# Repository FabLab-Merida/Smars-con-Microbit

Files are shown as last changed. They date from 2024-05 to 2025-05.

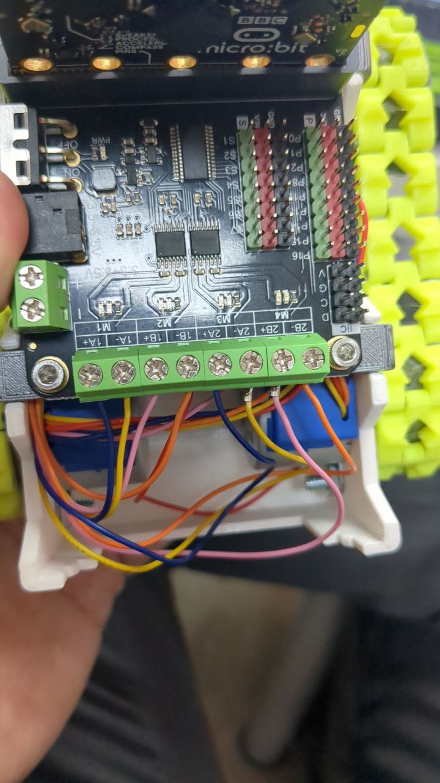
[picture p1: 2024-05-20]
Code/MotorPasoAPaso/CableadoMotorPasoAPaso.jpg

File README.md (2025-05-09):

# Smars con Microbit
 Smars with Microbit project we did for the CITlab centers (Extremadura)
 Smars con Microbit de los proyectos CITlab

 Updates:
   * Added magnetic gripper, a modification that requires the servo arm from the capacitive sensor and ⌀8mm magnets.
 
 Other Links//Otros links:
   * Original SMARS: https://www.thingiverse.com/thing:2662828
   * TPU/Rubber wheels: https://www.thingiverse.com/thing:3313618
   * Original Soil Moisture sensor: https://www.thingiverse.com/thing:2829488
   * Forklift Mod: https://www.thingiverse.com/thing:3027255

 
 PXL_20240521_102033709 MP 
 PXL_20240521_095141264~2

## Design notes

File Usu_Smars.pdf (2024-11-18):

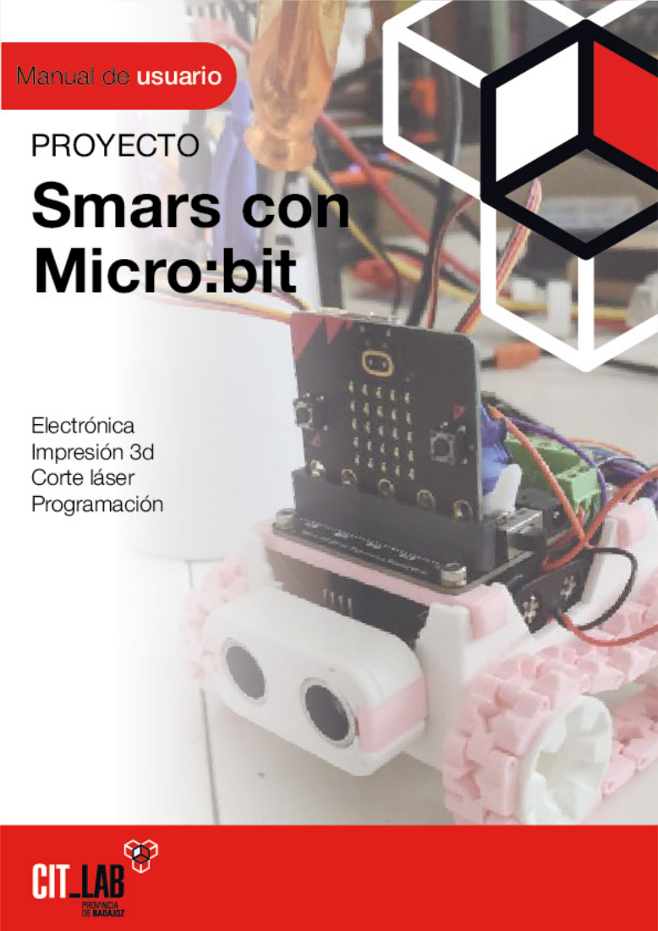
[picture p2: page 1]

# COMPONENTES

2

Este manual ha sido realizado por el equipo de la asociación FABlab Mérida para el proyecto CITLab de la Diputación de Badajoz.
Equipo técnico: Alberto Cañaveras Solís, Carlos Gómez-Landero Hernández, Javier García González, Javier García Arias, Javier Conejero Rodríguez, Juan Luis Arenas Sánchez, Pablo Augusto Gordillo Caro y Víctor Gallardo Sánchez.
Redacción de contenidos: Javier García González. Diseñador gráfico: Javier García González.
Maquetación: Javier García González.
Revisión: Javier García Arias, Juan Luis Arenas Sánchez, Julián Ortega Durán, Mercedes García Burrel y Víctor Gallardo Sánchez.
Todos los nombres propios de programas, sistemas operativos, equipos hardware, etc. que aparecen en este libro son marcas registradas de sus respectivas compañías u organizaciones.
Manual de usuario del Proyecto SMARS © 2024 by FA-Blab Mérida is licensed under CC BY-NC-SA 4.0

# ÍNDICE

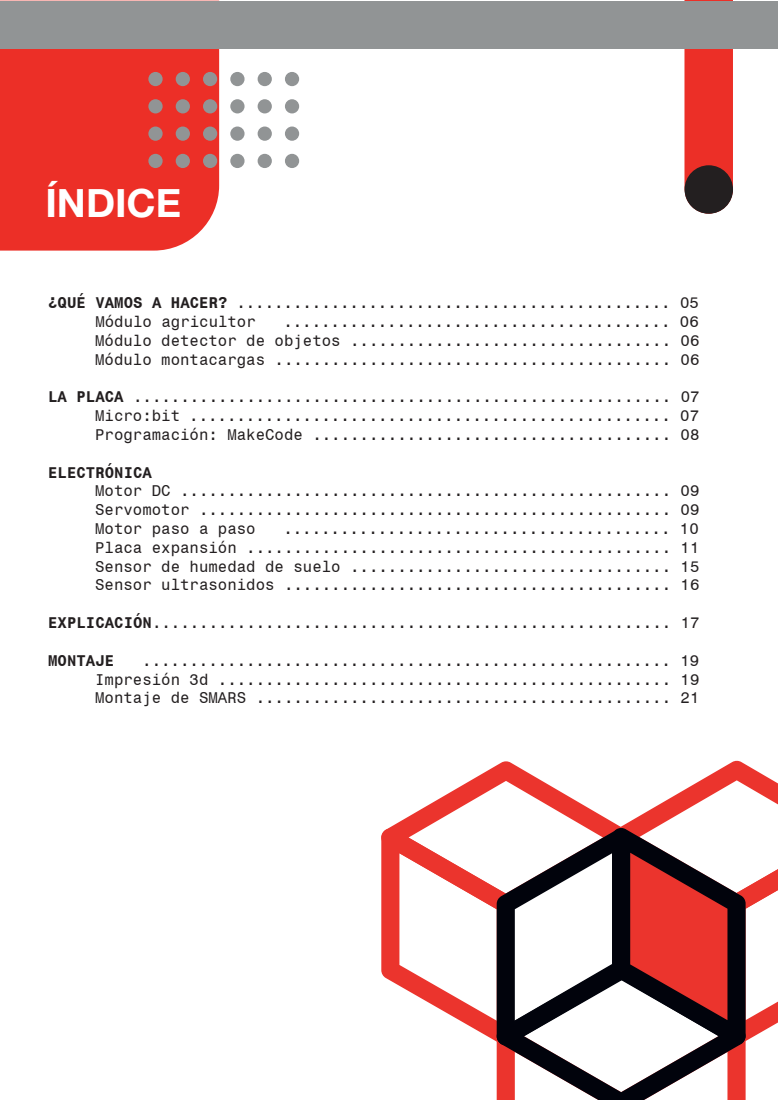
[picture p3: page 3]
ELECTRÓNICA

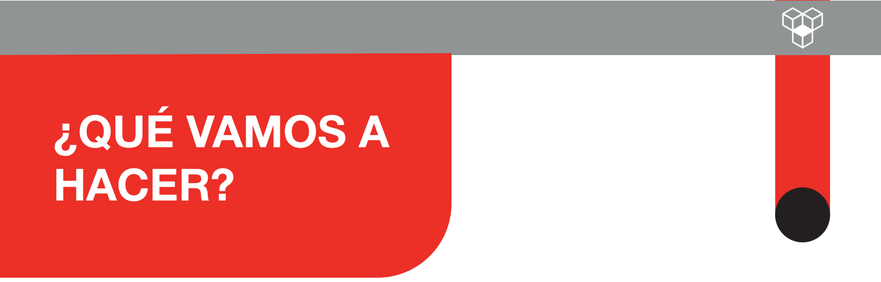
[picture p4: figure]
¿QUÉ VAMOS A HACER?

5

Los SMARS son un proyecto abierto donde han colaborado muchas personas que tienen como objetivo montar vehículos robóticos dirigidos a la educación. Estos robots están creados a partir de ensamblajes modulares sin necesidad de tornillos.
En este proyecto se pretende construir un smars basándonos en micro:bit con el que conocer las posibilidades de esta placa para la educación en programación y robótica. Además, se ofrecen distintas alternativas para que sea un proyecto dinámico y modular, como inicio al mundo de los SMARS.

Temática

Impresión 3d

Programación
básica

Electrónica
básica

Robótica

Materiales

Filamento PLA de tipos

Filamento TPU (opcional)

Tornillos M3x5mm | x4
Portapilas 4xAA | x1
Pilas AA | x4

Electrónica

Micro:bit | x1

Placa de expansión
Micro:bit Motor Expansion
| x1
Motor* | x2

# Smars básico

* Para empezar, se han añadido diversas opciones de montaje de motores:
- Servomotor 360º
- Motor paso a paso
- Motor DC 6V 150RPM
Cada uno de los motores requiere de una programación y modelo distinto, que se debe tener en cuenta en el desarrollo del prototipo.

# COMPONENTES

6

# ¿QUÉ VAMOS A HACER?

Materiales

Filamento PLA dos colores

Electrónica

Sensor capacitivo humedad

# Módulo agricultor

Con este módulo, se añade un sensor de humedad de tierra que puede pincharse en el suelo para comprobar su humedad y mapear la humedad del suelo siguiendo un recorrido.

Materiales

Filamento PLA dos colores

Materiales

Filamento PLA de dos tipos

Electrónica

Sensor de ultrasonidos . x1

Electrónica

Motor DC 6V 60RPM M3 5cm x1

# Módulo detector de objetos

# Módulo montacargas

Con este módulo se añade un sensor de ultrasonidos que permite la detección de objetos frente al SMARS y la posibilidad de esquivarlo.

Con este módulo, se puede sujetar objetos del suelo para desplazarlos de un lado a otro.

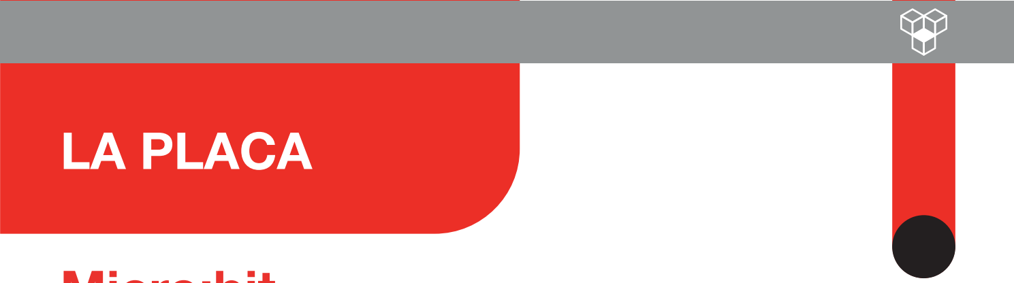
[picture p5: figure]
LA PLACA

7 7

Micro:bit es una pequeña placa de desarrollo diseñada por la BBC para enseñar programación y computación en la educación primaria y secundaria. Es una herramienta educativa que permite a los estudiantes aprender conceptos básicos de programación y electrónica de una manera práctica y divertida.

# Micro:bit

Entradas del micro:bit y sensores integrados:

Echa un vistazo al QR si quieres saber más.

Micro:bit posee varias entradas y salidas para conectarse con otros dispositivos:
3 Entradas salidas digitales
4 Salida de 3V
5 Pin de tierra
También tiene sensores integrados para tener una iniciación más rápida.
Frontal
1 Botón A y B
2 Matriz de 5x5 leds
6 Logo con sensor táctil
Trasera
1 Antena de radio y bluetooth
2 Sensor de temperatura
3 4 Acelerómetro y osciloscopio 5 Pines
6 Entrada Micro USB
9 Entrada de batería
Altavoz
Micrófono
Botón de reset

11
12
13

# LA PLACA

# Programación: MakeCode

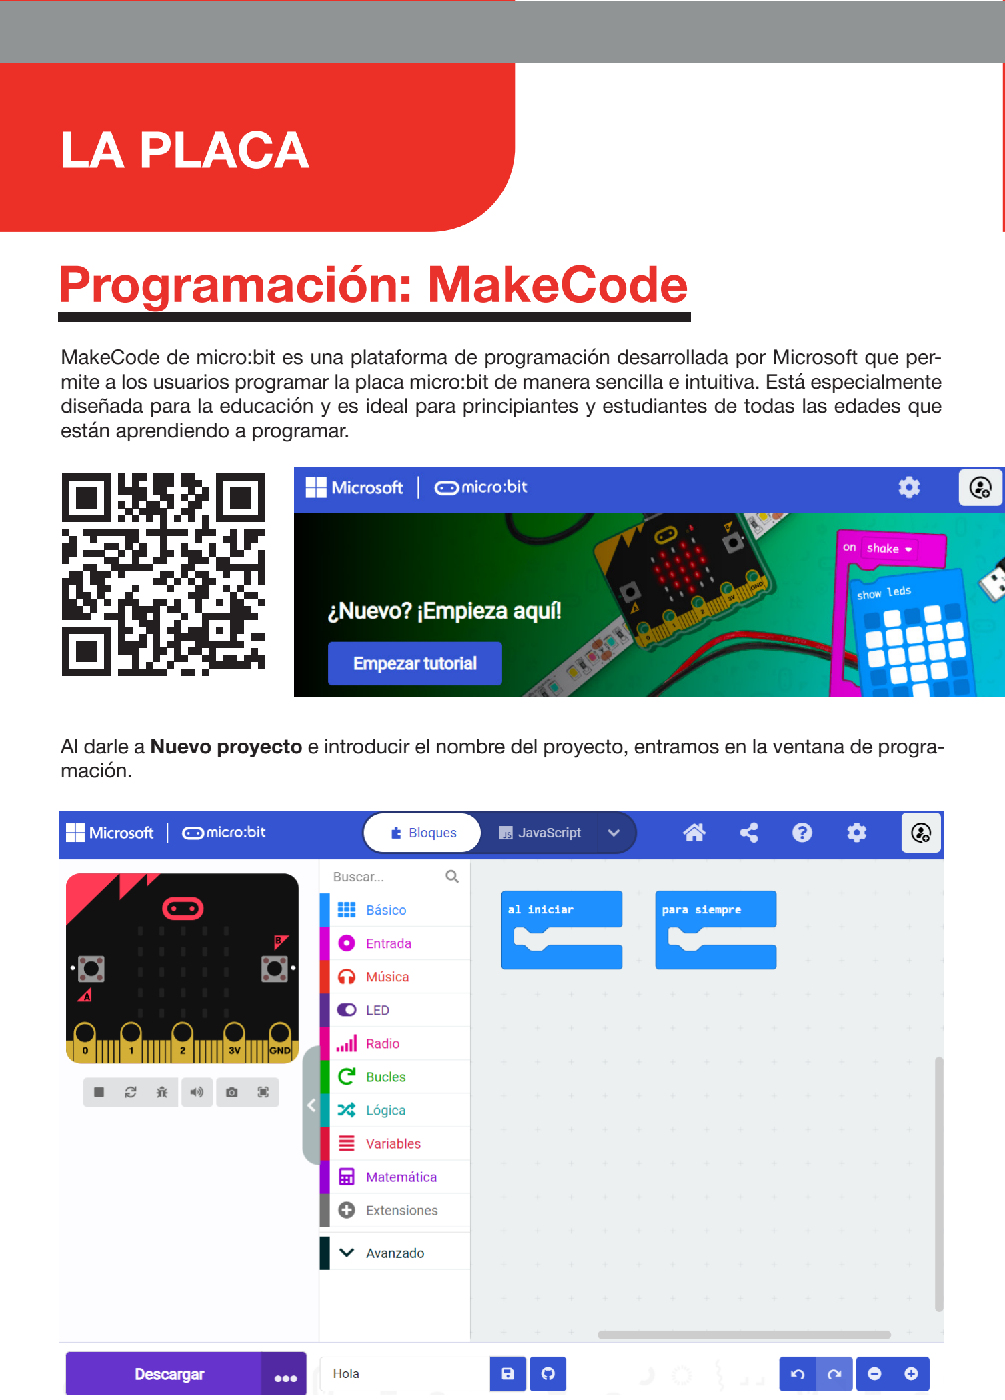
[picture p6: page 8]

MakeCode de micro:bit es una plataforma de programación desarrollada por Microsoft que permite a los usuarios programar la placa micro:bit de manera sencilla e intuitiva. Está especialmente diseñada para la educación y es ideal para principiantes y estudiantes de todas las edades que están aprendiendo a programar.

Al darle a Nuevo proyecto e introducir el nombre del proyecto, entramos en la ventana de programación.

9

Microbit: las salidas PWM
«PWM» significa «Modulación de Ancho de Pulso» en inglés (Pulse Width Modulation). Es una técnica utilizada en electrónica para controlar la cantidad de energía entregada a un dispositivo, mediante la variación del ancho de los pulsos de una señal eléctrica. Posee un funcionamiento distinto al del resto de pines digitales si se le indica.

Un motor DC es un motor que funciona por corriente contínua. Su propia fabricación hace que, si se le alimenta con una mayor tensión, se obtengan mayores revoluciones. Solo requiere de una entrada de corriente y una de tierra

Estos dispositivos son comúnmente utilizados en proyectos y dispositivos que requieren movimiento controlado, como juguetes, robots, modelismo, y otras aplicaciones.

La característica principal de un servomotor es su capacidad para girar hasta un ángulo determinado en respuesta a señales eléctricas. La mayoría de los servomotores comerciales para proyectos electrónicos tienen un rango de movimiento de 0 a 180 grados, aunque también existen modelos que pueden girar 360 grados. En nuestro proyecto utilizaremos dos servomotores que deben ser de 360º para mover las ruedas. En caso de que sean de 180º, este proyecto no sería posible con este tipo de motor.

# Servomotor

Pines de un servo
- Señal (PWM): Pin que le proporciona la señal digital que le indicará al servomotor la posición a la que debe girar. Debe conectarse a un pin PWM.
- Positivo (+): entrada de 5V del Arduino.
- Negativo (-): salida a GND del Arduino.
+

s

Un servomotor es un dispositivo que permite controlar y posicionar un eje en ángulos específicos. A diferencia de los motores convencionales, los servomotores están diseñados para un control preciso de la posición angular.

Cómo funciona un servomotor:

10

# COMPONENTES

# Motor Paso a paso

Un motor paso a paso es un tipo de motor similar a los servos. Al igual que ellos, se puede regular la posición del eje del motor con mucha precisión. Para ello, en vez de utilizar ángulos, se emplean pasos, que son pequeños desplazamientos de rotación.
En nuestro caso, los motores tienen 20 posiciones distintas.

Pines de un motor paso a paso
Este tipo de motores requiere usualmente de una placa intermedia para funcionar al que se conectan siguiendo la distribución indicada abajo:

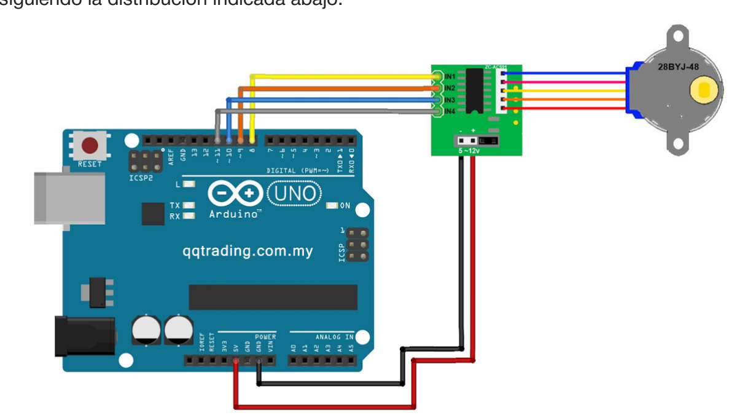
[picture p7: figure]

Sin embargo, en nuestro proyecto utilizaremos una placa de expansión de motores adaptada a micro:bit.

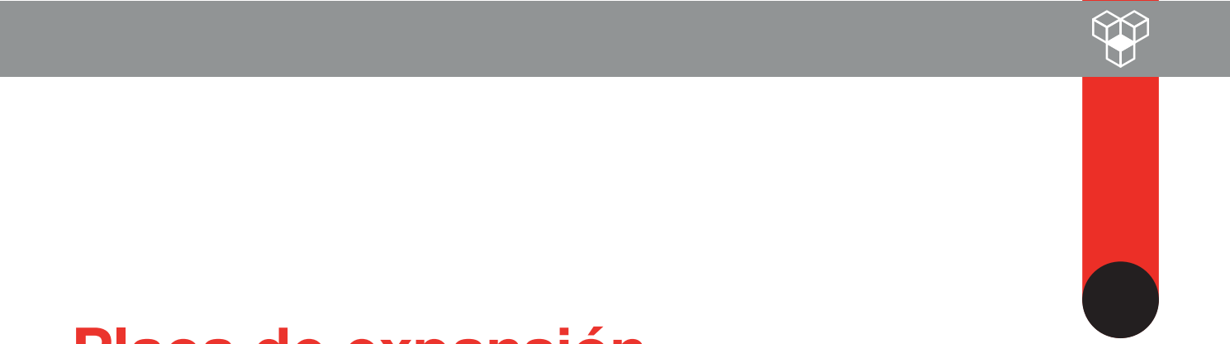
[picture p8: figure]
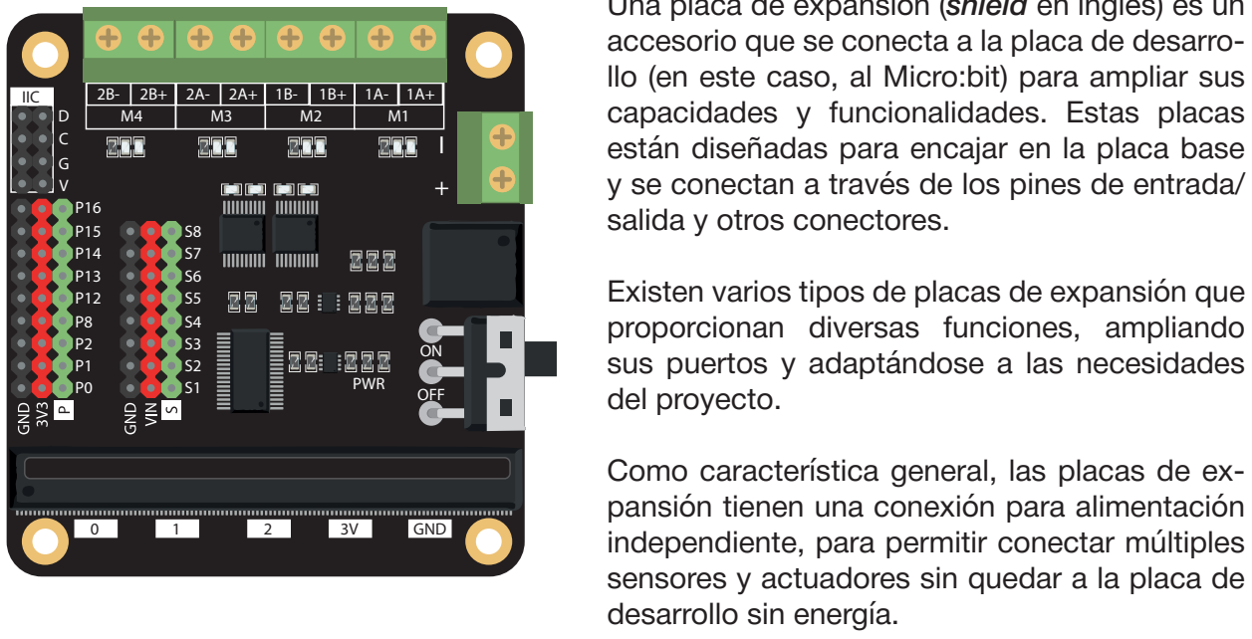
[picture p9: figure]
capacidades y funcionalidades. Estas placas; salida y otros conectores.; proporcionan diversas funciones, ampliando; del proyecto.; independiente, para permitir conectar múltiples; desarrollo sin energía.; IIC; GND; OFF PWR

11

Una placa de expansión (shield en inglés) es un accesorio que se conecta a la placa de desarrollo (en este caso, al Micro:bit) para ampliar sus están diseñadas para encajar en la placa base y se conectan a través de los pines de entrada/

Existen varios tipos de placas de expansión que sus puertos y adaptándose a las necesidades

Como característica general, las placas de expansión tienen una conexión para alimentación sensores y actuadores sin quedar a la placa de

# Placa de expansión

0 | 1 | 2 | 3V | GND

Funcionamiento de la placa de expansión

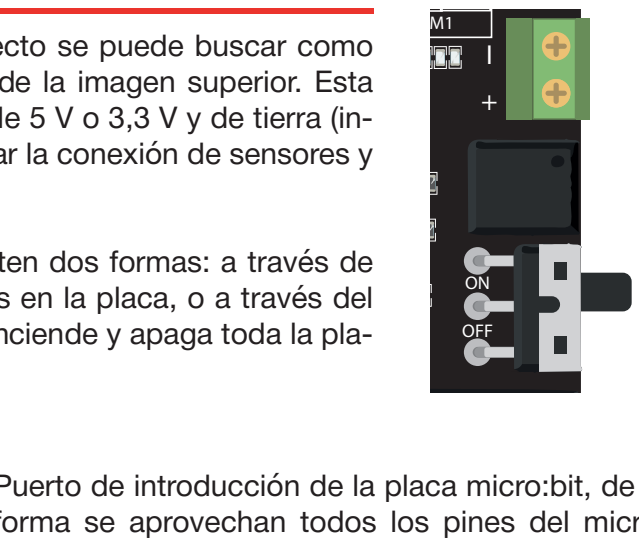
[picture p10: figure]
OFF PWR

La placa que se quiere utilizar en este proyecto se puede buscar como Micro:Bit Motor Expansion y tiene la forma de la imagen superior. Esta placa añade a cada pin del micro:bit un pin de 5 V o 3,3 V y de tierra (indicado en las placas como GND), para facilitar la conexión de sensores y actuadores.
Para alimentar esta placa de expansión existen dos formas: a través de dos cables introducidos en el - y + indicados en la placa, o a través del puerto de al lado. Existe un interruptor que enciende y apaga toda la placa.

Puerto de introducción de la placa micro:bit, de esta forma se aprovechan todos los pines del micro:bit para conectar multitud de sensores y actuadores.

# COMPONENTES

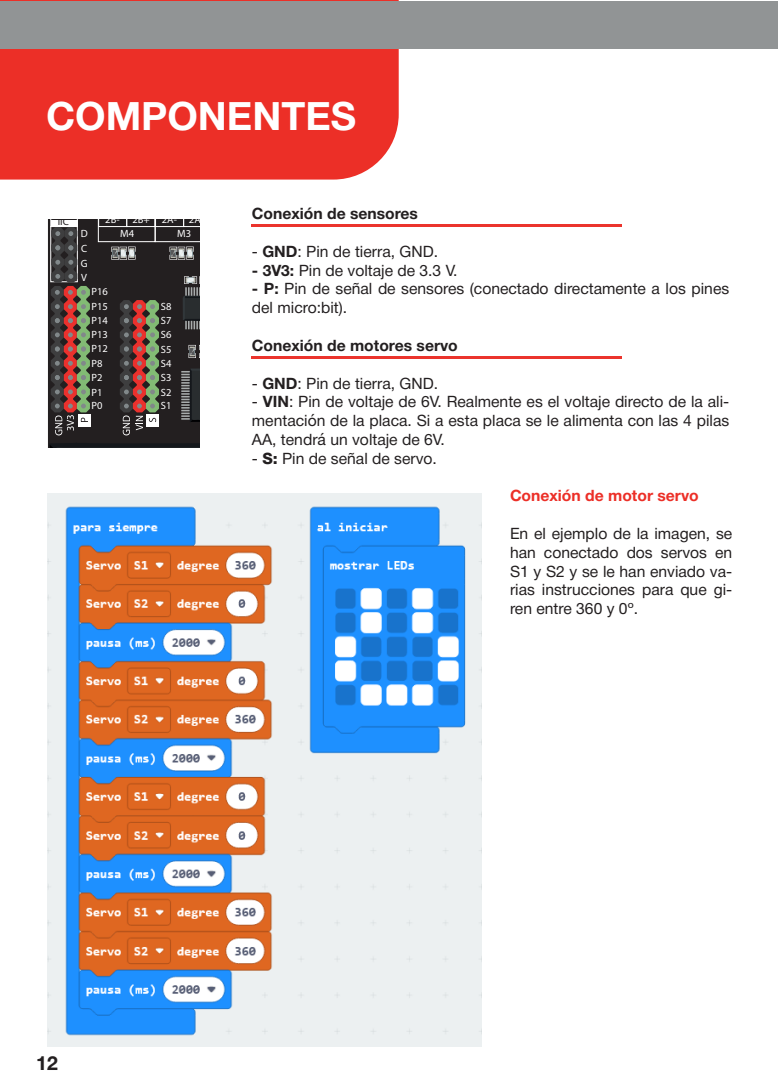
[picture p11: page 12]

Conexión de sensores
- GND: Pin de tierra, GND.
- 3V3: Pin de voltaje de 3.3 V.
- P: Pin de señal de sensores (conectado directamente a los pines
del micro:bit).
Conexión de motores servo
- VIN: Pin de voltaje de 6V. Realmente es el voltaje directo de la ali-
mentación de la placa. Si a esta placa se le alimenta con las 4 pilas
AA, tendrá un voltaje de 6V.
- S: Pin de señal de servo.

Conexión de motor servo
En el ejemplo de la imagen, se
han conectado dos servos en
S1 y S2 y se le han enviado va-
rias instrucciones para que gi-
ren entre 360 y 0º.

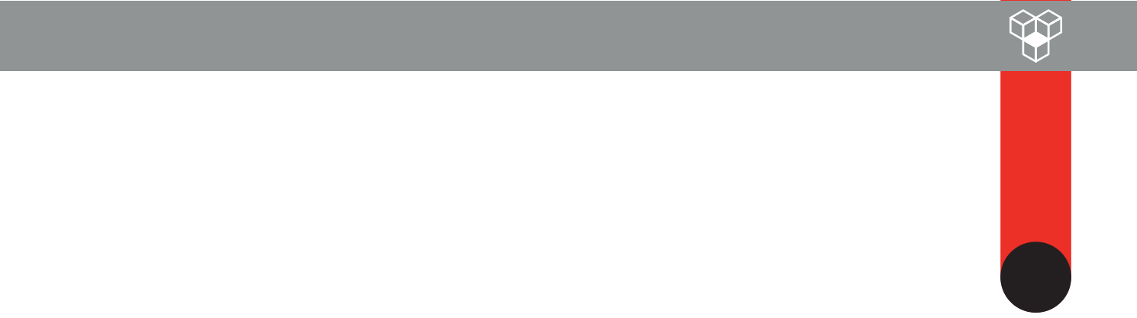
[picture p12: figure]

13

2B-M4

IIC

2B+ 2A-M3

2A+

1B-M2

1B+ 1A-M1

1A+
D

Conexión de motores DC/Paso a paso
En estas conexiones es posible conectar cuatro motores DC o dos motores paso a paso.
Conexión de motor DC:
Se utiliza la conexión de M1. Si se cambia la posición del positivo con el negativo, se cambia la dirección del motor. Es posible conectar cuatro motores distintos (M1, M2, M3 y M4).

1A-

M11A+

En el ejemplo de la imagen, se han conectado dos motores DC en M1 y M2 y se le han enviado varias instrucciones para que hacia un lado o hacia otro a toda velocidad, que corresponde con 255.
- La opción CW es para girar hacia un lado el motor.
- La opción CCW para girar para el otro.

# COMPONENTES

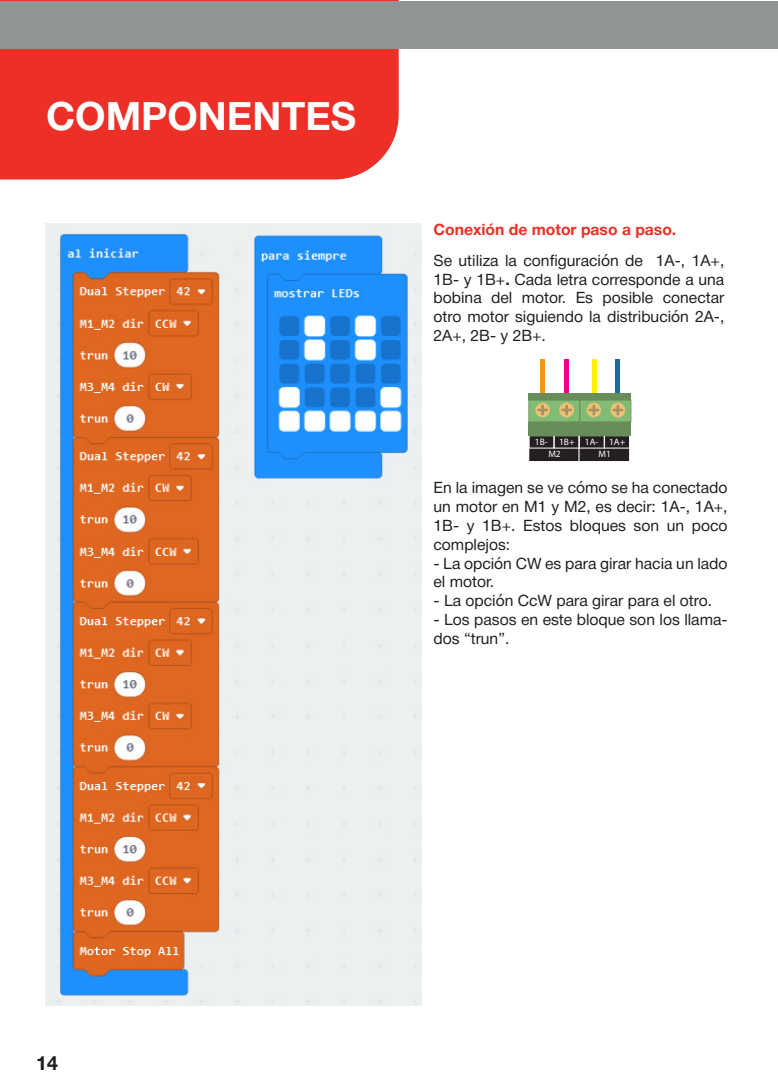
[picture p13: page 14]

Conexión de motor paso a paso.
Se utiliza la configuración de 1A-, 1A+,
1B- y 1B+. Cada letra corresponde a una
bobina del motor. Es posible conectar
otro motor siguiendo la distribución 2A-,

En la imagen se ve cómo se ha conectado
un motor en M1 y M2, es decir: 1A-, 1A+,
1B- y 1B+. Estos bloques son un poco
complejos:
- La opción CW es para girar hacia un lado
el motor.
- La opción CcW para girar para el otro.
- Los pasos en este bloque son los llama-
dos “trun”.

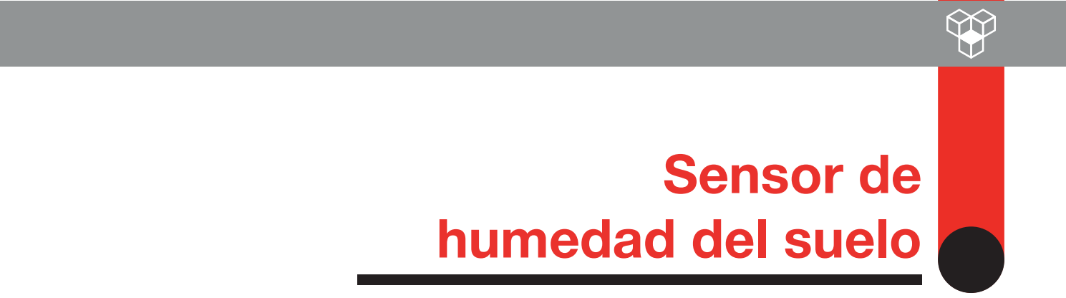
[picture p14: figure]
Sensor de humedad del suelo

Este sensor mide la humedad del suelo a través de una propiedad del agua: es conductora de la electricidad. Cuanta más agua tiene un suelo, más conductor es.
Este sensor mide la corriente que pasa por él y nos da un valor en función de esa corriente.
Este sensor es un elemento de entrada analógica.

Funcionamiento del sensor de Humedad
La lectura del sensor es realmente sencilla. Únicamente tenemos que realizar su lectura empleando uno de los puertos P. En este ejemplo, realizamos la lectura del sensor y mostramos el valor por pantalla. Las conexiones necesarias están indicadas en la imagen.

Para más información de este sensor, escanea el QR.

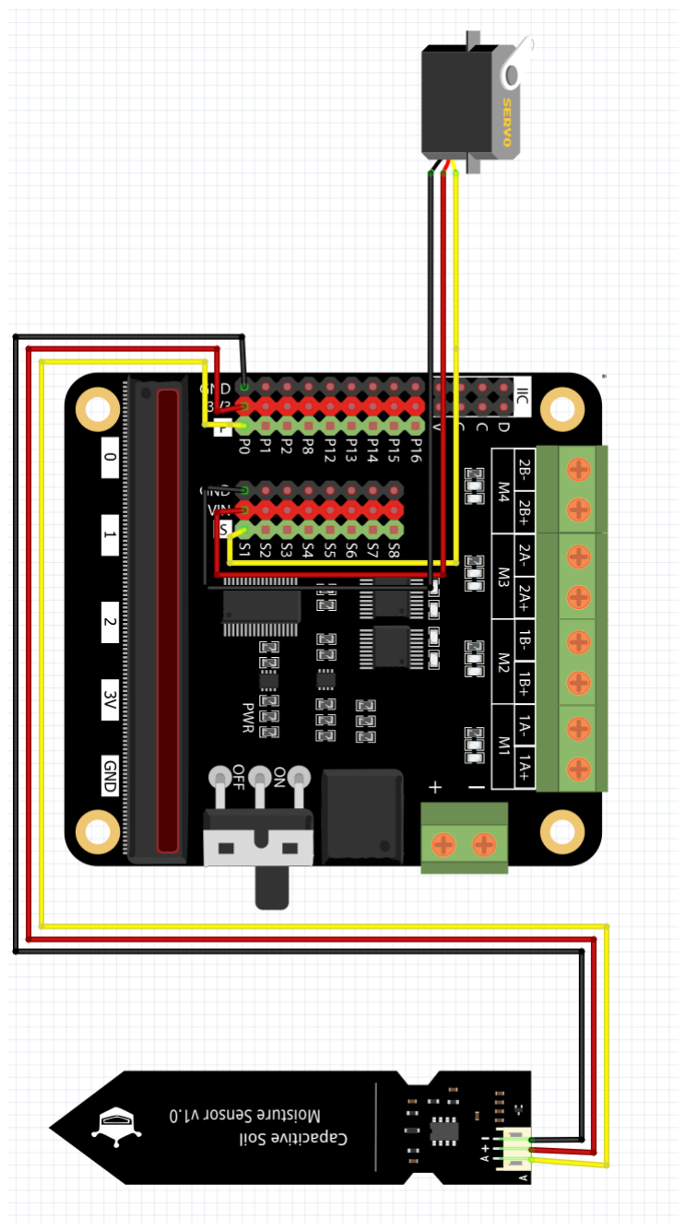
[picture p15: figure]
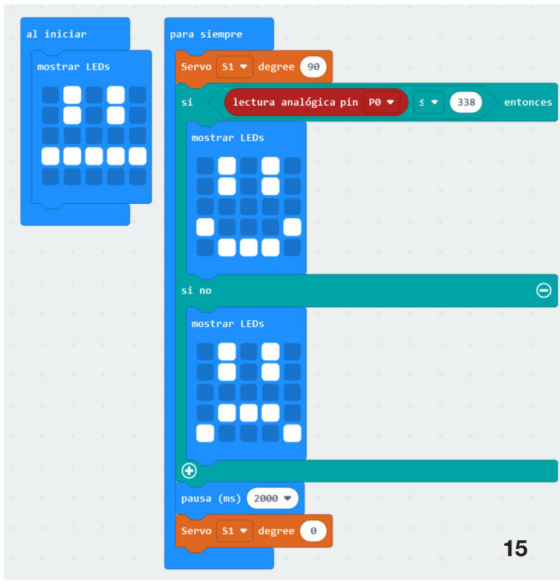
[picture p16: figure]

# COMPONENTES

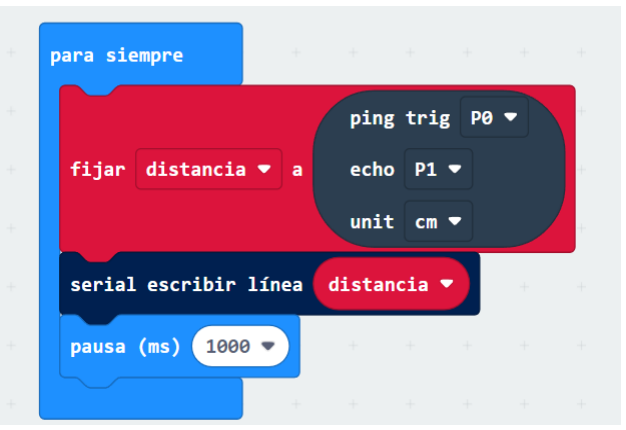
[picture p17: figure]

16

Este sensor utiliza ondas de ultrasonidos para medir distancias. Emite y recibe estas ondas y mide el tiempo que tarda en recibir el eco de la señal. De esta forma, junto con la velocidad del sonido, nos permite conocer la distancia recorrida por la onda entre los objetos con los que rebota y el sensor. En nuestro proyecto, los utilizaremos para detectar al robot contrario.

# Sensor ultrasonidos

Funcionamiento del sensor de ultrasonidos

Este en un sensor que requiere de cuatro pines:
- Positivo (VCC): entrada de tensión, en micro:bit está preparado para funcionar con 3,3 V.
- Trig (Trigger): activador, pin por donde le entra la orden de enviar una onda. Conéctalo a P0.
- Echo (Echo): eco, pin por donde el sensor envía el cálculo del tiempo que ha tardado en recibir la onda. Conéctalo al P1.
- Tierrra (GND): salida a GND del micro:bit.

Echa un vistazo al QR si quieres saber más.

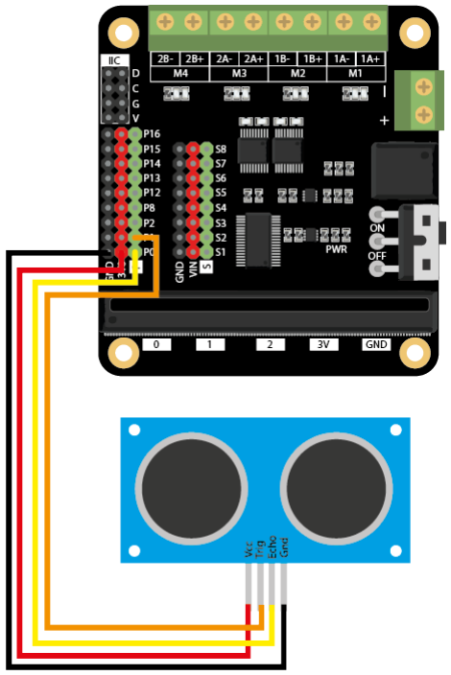
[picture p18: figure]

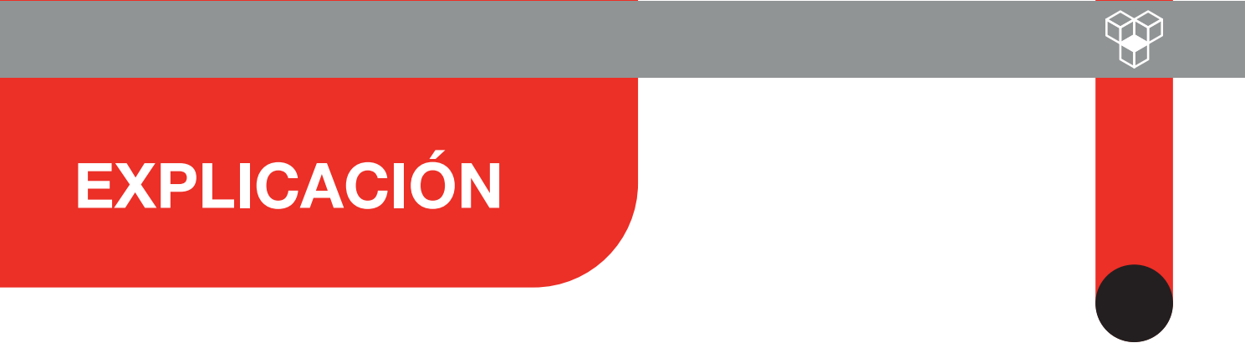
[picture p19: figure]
EXPLICACIÓN

17

El propósito final de este proyecto es crear robots que sean capaces de moverse utilizando un micro:bit como cerebro y posean distintas funcionalidades según los módulos que se quieran fabricar. Para el movimiento del robot, simplemente hay que conocer las instrucciones del movimiento del motor (antes explicados).
Además, se puede utilizar el bluetooth y la radio del microbit para conectarse a un móvil u otro microbit para mandarle instrucciones de movimiento.

Este módulo consiste en un brazo robótico controlado por un solo servomotor. Este brazo pincha un sensor de humedad de tierra en la tierra (blandita tipo arena porque esto es un juguete) y mide la humedad de la misma.
En función del nivel de humedad, pondrá carita triste o carita contenta en la matriz led del micro:bit.

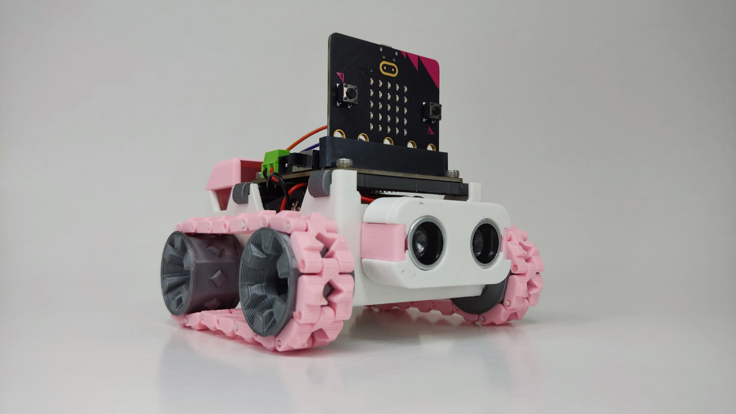
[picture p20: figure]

Este módulo consiste en añadir un sensor de ultrasonidos al robot para que no choque contra objetos cuando se mueve.

# Módulo agricultor

# Módulo ultrasonidos

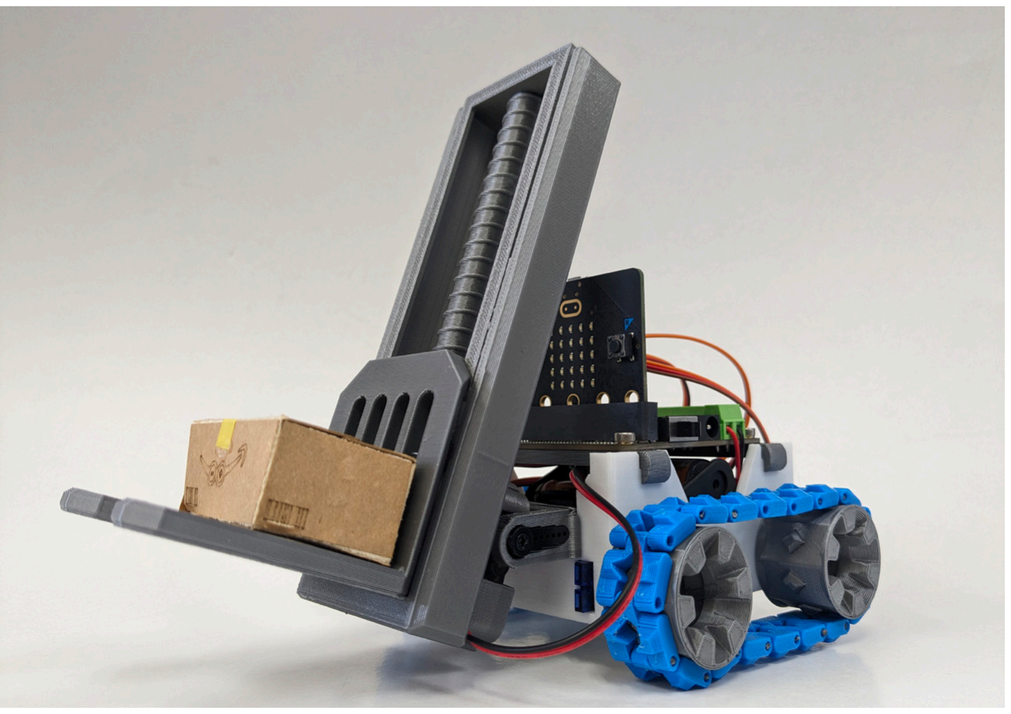
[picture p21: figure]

18

# EXPLICACIÓN

# Módulo montacargas

Este módulo consiste en añadir un toro de carga al smars, haciendo con ello un pequeño transportín que puede cargar, transportar y descargar pequeños objetos.
Su funcionamiento consiste en un motor DC para elevar el toro y un motor servo para girarlo parcialmente, haciendo que la carga no se caiga hacia delante.

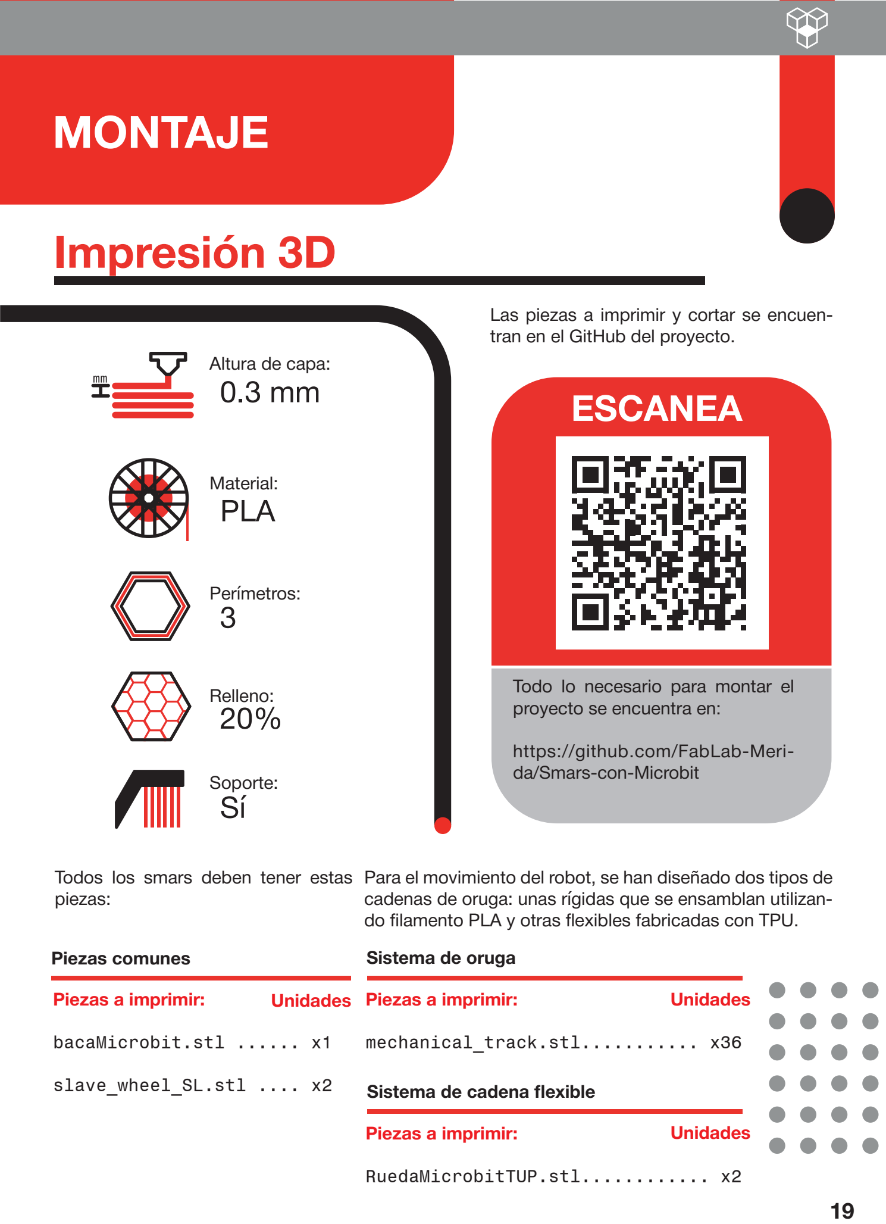
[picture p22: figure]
tran en el GitHub del proyecto.; Impresión 3D; PLA; Altura de capa:; Material:; Perímetros:; Relleno:; Soporte:; Piezas a imprimir:; mechanical_track.stl........... x36; RuedaMicrobitTUP.stl............ x2; Todos los smars deben tener estas piezas:; Unidades; Sistema de oruga; Sistema de cadena flexible; bacaMicrobit.stl ...... x1; slave_wheel_SL.stl .... x2; Piezas comunes; MONTAJE; Todo lo necesario para montar el proyecto se encuentra en:; https://github.com/FabLab-Meri- da/Smars-con-Microbit; ESCANEA

Las piezas a imprimir y cortar se encuen-

Para el movimiento del robot, se han diseñado dos tipos de cadenas de oruga: unas rígidas que se ensamblan utilizando filamento PLA y otras flexibles fabricadas con TPU.

20

# MONTAJE

Piezas a imprimir:

ChassisServo.stl | x1
SMARS_servo_wheel.stl | x2

Piezas a imprimir:

ChassisStepper.stl | x1
SMARSTrunk.stl | x1

SmarsMasterWheelStepper.stl..... x2

Para cada tipo de motor, se ha diseñado un chasis distinto:

Unidades

Unidades

Motor Servo

Motor Paso a paso

Piezas a imprimir:

ChassisDC.stl | x1
master_wheel.stl | x2

Unidades

Motor DC

Piezas a imprimir:

SmarsCapacitiveEdit.stl ........ x1

fork_lift_e.stl | x1
fork_lift_f.stl | x1

holder_soil_moisture.stl ....... x1

smarsCapacitive2.stl | x1
ub2.stl | x1
ut2.stl | x1

Piezas a imprimir:

ultrasonic_2b_V2.stl | x1
ultrasonic_1.stl | x1

Piezas a imprimir:

fork_lift_a.stl | x1
fork_lift_b.stl | x1
fork_lift_c.stl | x1
fork_lift_d.stl | x1
fork_lift_e.stl | x1
fork_lift_f.stl | x1

Para cada módulo, se deben imprimir ciertas piezas:
Sensor capacitivo de humedad

Módulo ultrasonidos

Módulo montacargas

Unidades

Unidades

Unidades

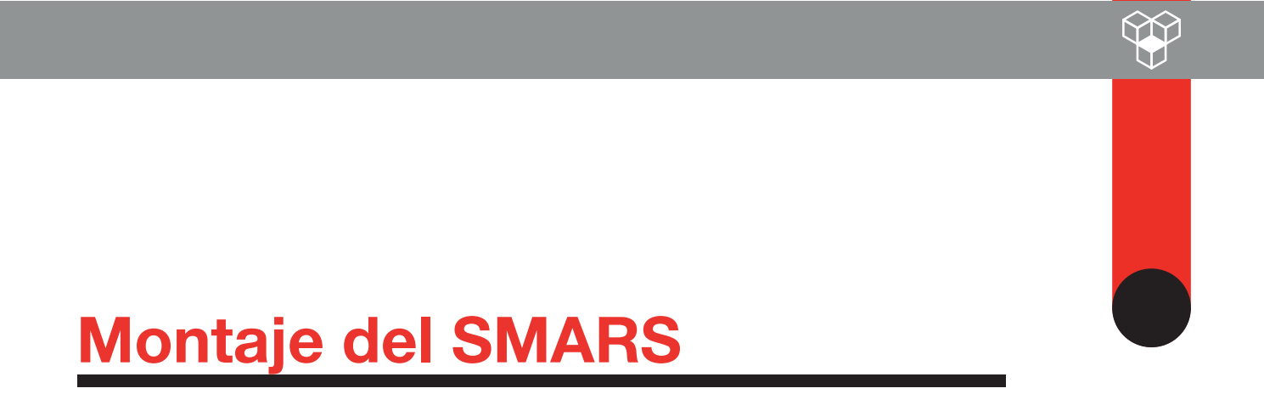
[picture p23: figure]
Montaje del SMARS

21

El material que necesitas si quieres montarlo con este tipo de motores son:

El material que necesitas si quieres montarlo con este tipo de motores son:
Unidades

Unidades

Hardware

Electrónica

bacaMicrobit | x1
slave_wheel_SL | x2
ChassisServo | x1
SMARS_servo_wheel | x2
Tornillo M3x5mm | x4

Insertos térmicos M3x4mm ....... x4

Micro:bit | x1

Micro:Bit Motor Expansion ...... x1

Servo Motor 360º | x2
Portapilas 4AA | X1
Pilas AA | x4
Chasis SMARS con Motores Servo | Chasis SMARS con Motores Paso a Paso
Hardware | Unidades
bacaMicrobit | x1
slave_wheel_SL | x2
ChassisStepper | x1
SMARSTrunk | x1

SmarsMasterWheelStepper ........ x2

Tornillo M3x5mm | x4

Insertos térmicos M3x4mm ....... x4

Tornillos M4x5mm | x4
Tuercas M4 | x4
Electrónica | Unidades
Micro:bit | x1

Micro:Bit Motor Expansion ...... x1

Motor paso a paso | x2
Portapilas 4AA | X1
Pilas AA | x4

22

Hardware | Unidades Electrónica | Unidades
bacaMicrobit | x1
slave_wheel_SL | x2
ChassisDC | x1
master_wheel | x2
Tornillo M3x5mm | x4

Insertos térmicos M3x4mm ....... x4

Tornillos M4x5mm | x4
Tuercas M4 | x4
Micro:bit | x1

Micro:Bit Motor Expansion ...... x1

Motor DC | x2
Portapilas 4AA | X1
Pilas AA | x4

Chasis SMARS con Motores DC

# MONTAJE

El material que necesitas si quieres montarlo con este tipo de motores son:

Hardware

Hardware

mechanical_track.stl | x36

Filamento PLA

RuedaMicrobitTUP | x2

Cadena de PLA

Cadena de TPU (flexible)

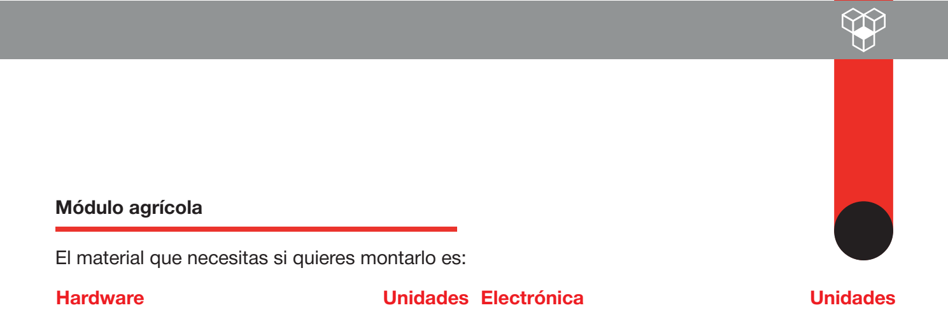
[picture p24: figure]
Unidades; Hardware; Electrónica; Módulo agrícola

23

Unidades

Unidades

Unidades

Unidades

Hardware

Hardware

Electrónica

Electrónica

SmarsCapacitiveEdit.stl ........ x1

fork_lift_e.stl | x1
fork_lift_f.stl | x1

holder_soil_moisture.stl ....... x1

smarsCapacitive2.stl | x1
ub2.stl | x1
ut2.stl | x1
ultrasonic_2b_V2.stl | x1
ultrasonic_1.stl | x1

Sensor capacitivo humedad de suelo
V1.2 | x1
Servomotor | x1
Sensor ultrasonidos | x1
Servomotor 90º | x1
Motor DC 6V 60RPM M3 5cm ....... x1

Módulo ultrasonidos

Módulo montacargas

El material que necesitas si quieres montarlo es:

El material que necesitas si quieres montarlo es:

El material que necesitas si quieres montarlo es:

fork_lift_a.stl | x1
fork_lift_b.stl | x1
fork_lift_c.stl | x1
fork_lift_d.stl | x1
fork_lift_e.stl | x1
fork_lift_f.stl | x1

# MONTAJE

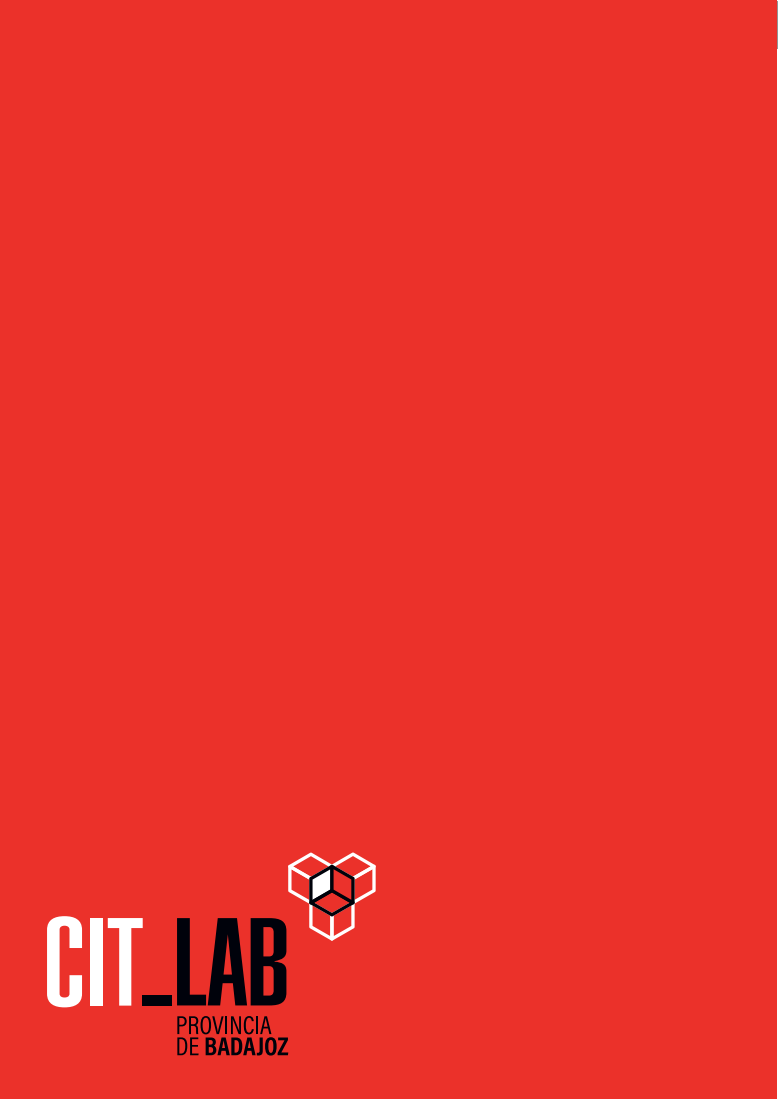
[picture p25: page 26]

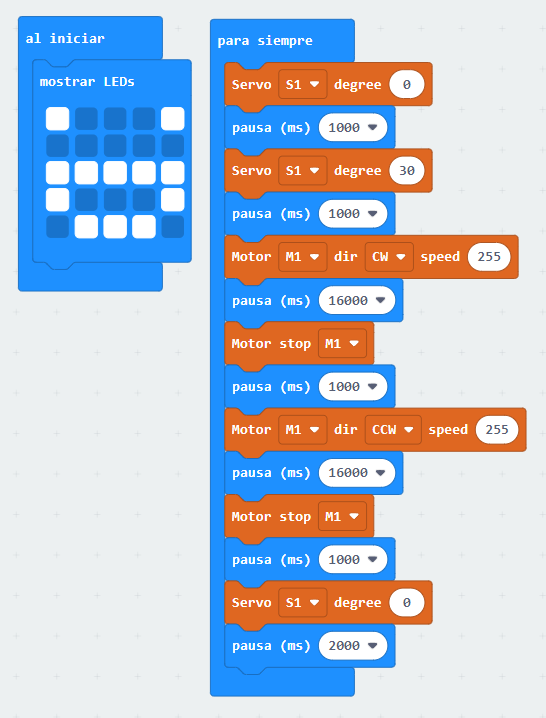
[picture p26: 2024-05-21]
Code/Modulo torito.PNG

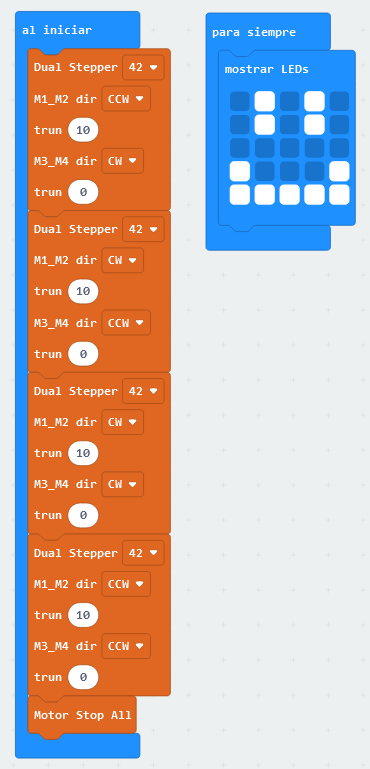
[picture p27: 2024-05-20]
Code/DemoPasoAPaso.PNG

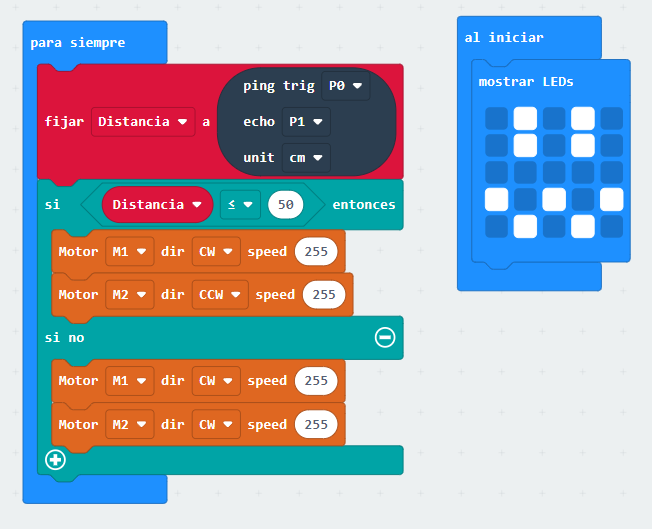
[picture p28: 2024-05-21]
Code/DemoUltrasonidos.PNG

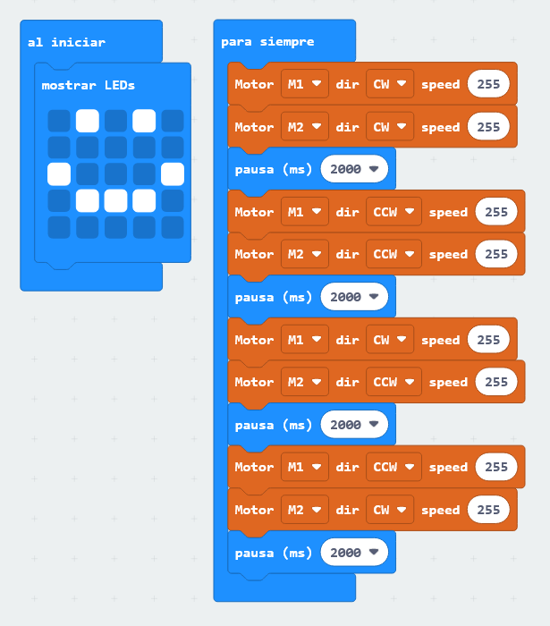
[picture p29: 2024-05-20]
Code/DemoDC.PNG

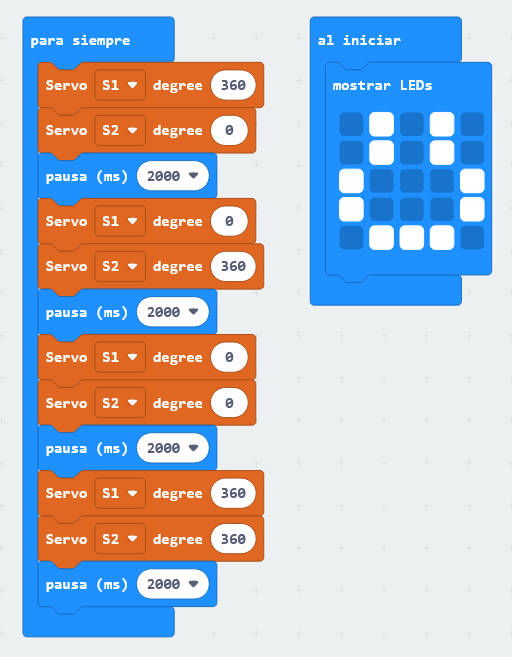
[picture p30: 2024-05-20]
Code/DemoServo.PNG

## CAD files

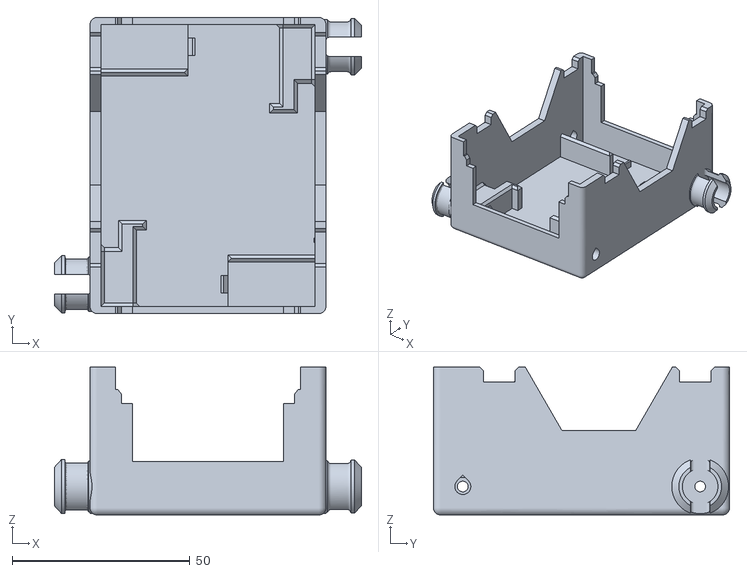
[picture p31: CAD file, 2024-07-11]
CAD/SmarsMicrobit/Chasis/DC/ChassisDC.stl
86.3 x 83.2 x 41.6

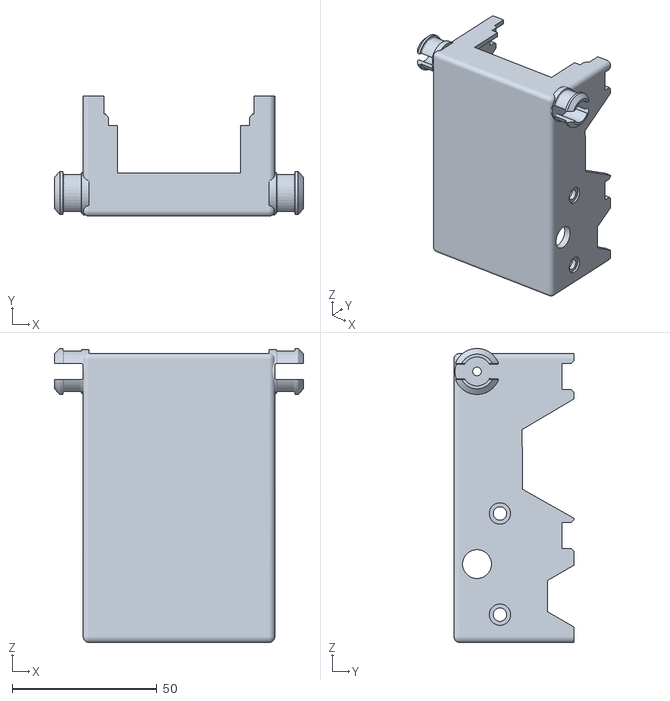
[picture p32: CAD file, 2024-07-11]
CAD/SmarsMicrobit/Chasis/PasoAPaso/ChassisStepper.stl
86.3 x 41.6 x 101.7

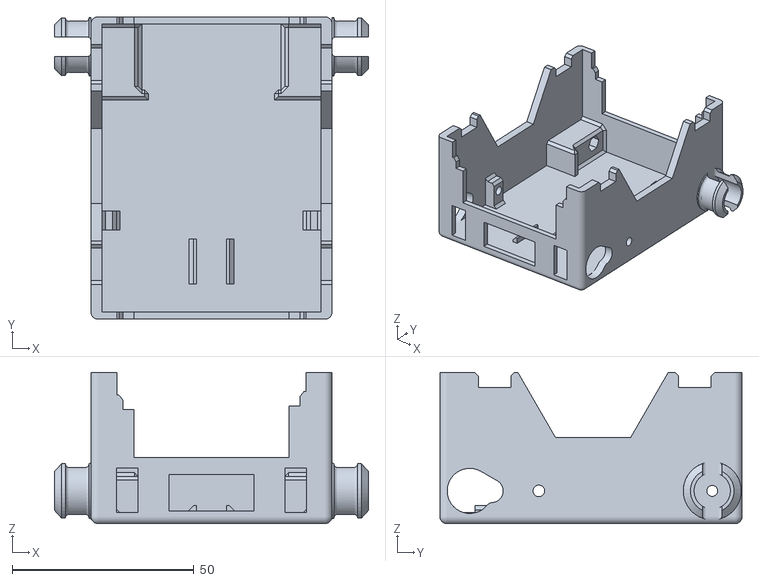
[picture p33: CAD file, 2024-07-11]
CAD/SmarsMicrobit/Chasis/Servo/ChassisServo.stl
86.3 x 83.1 x 41.6

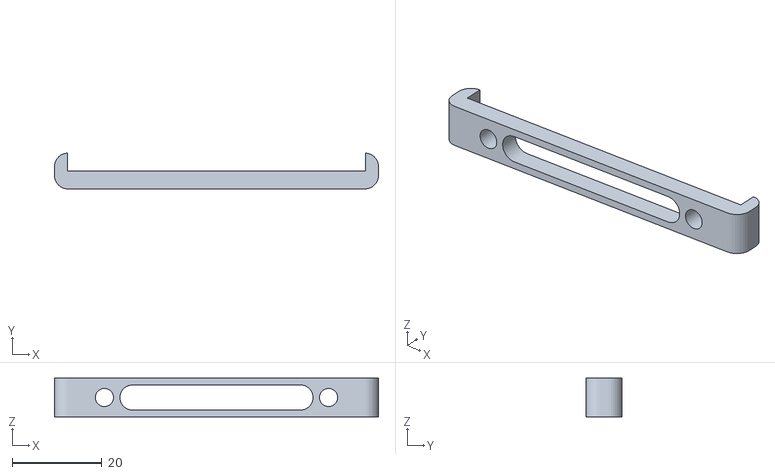
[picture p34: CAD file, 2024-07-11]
CAD/SmarsMicrobit/CommonMicrobitPieces/MicrobitHolder.stl
72.3 x 8.00 x 8.64

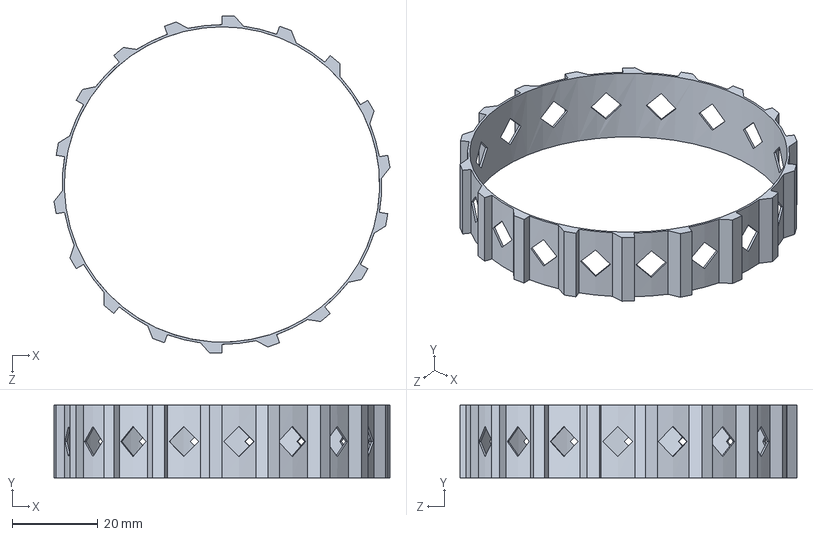
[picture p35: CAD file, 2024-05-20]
CAD/SmarsMicrobit/CommonMicrobitPieces/OrugaTPU/RuedaMicrobitTPU.SLDPRT
78.3 x 17.0 x 78.5 mm

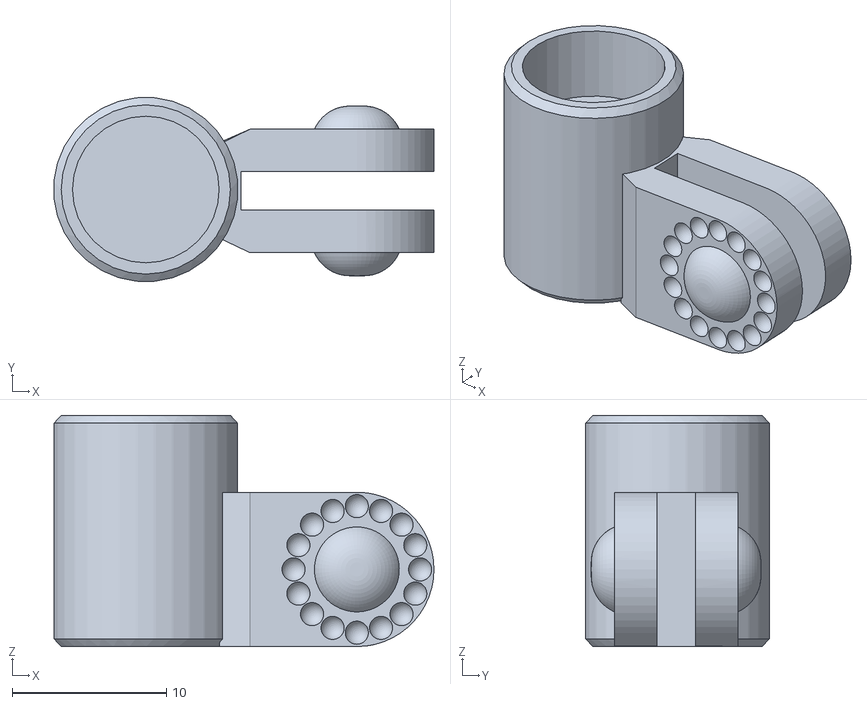
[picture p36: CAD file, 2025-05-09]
CAD/SmarsMicrobit/Sensores/MagnetGripper/MagnetGripper.stl
24.6 x 11.9 x 15.0

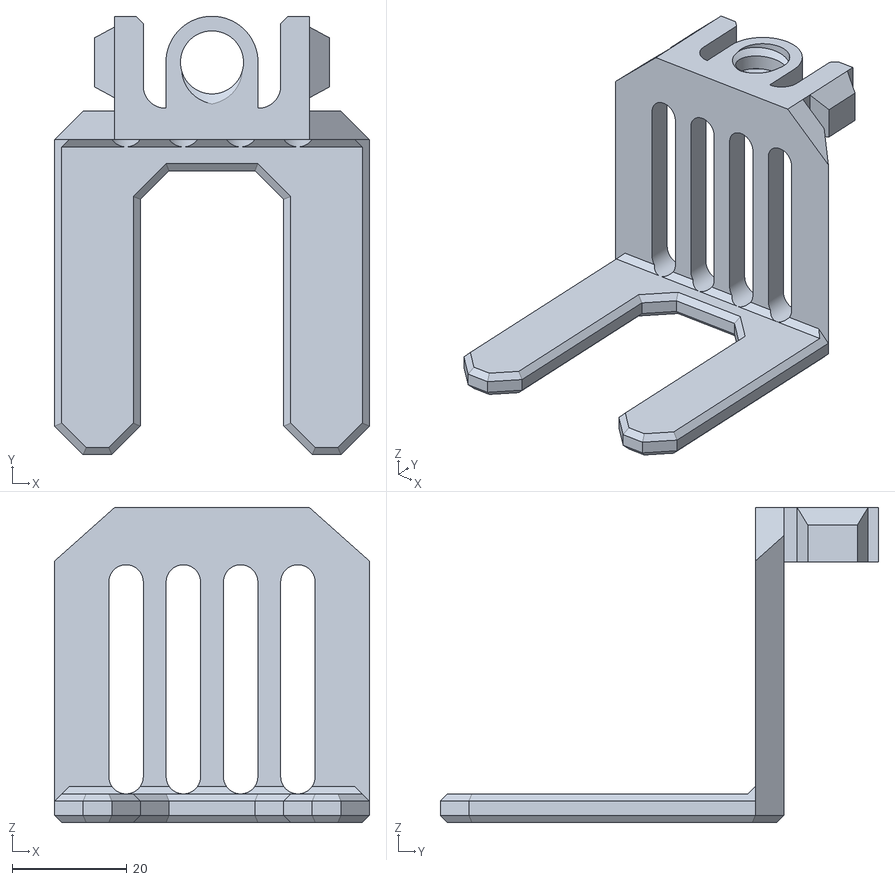
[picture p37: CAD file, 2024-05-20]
CAD/SmarsMicrobit/Sensores/Montacargas/fork_lift_d.stl
55.0 x 76.6 x 55.0

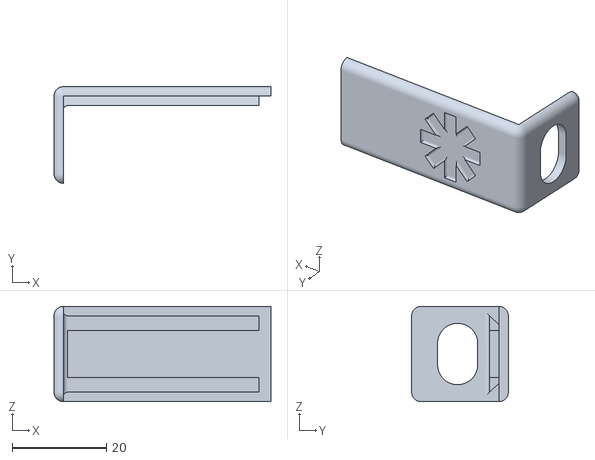
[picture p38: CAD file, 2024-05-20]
CAD/SmarsMicrobit/Sensores/Sensor SigueLineas/ir_sensor_b.stl
46.0 x 20.5 x 20.2

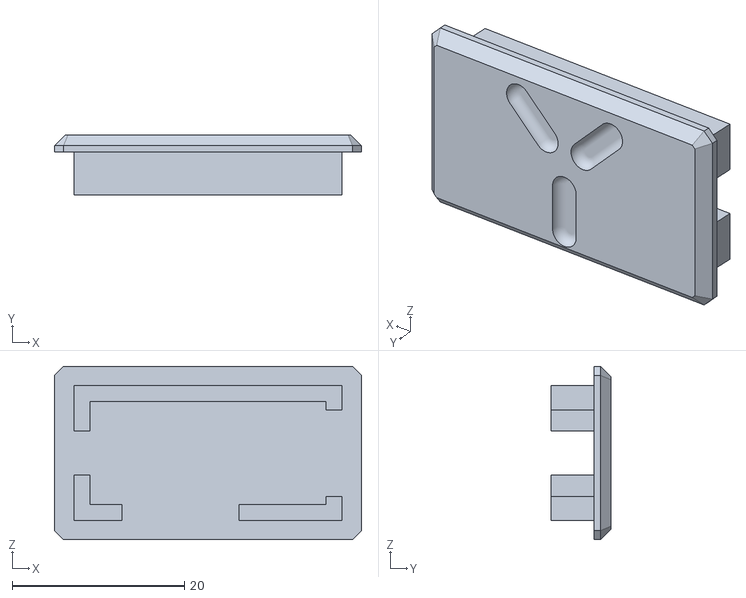
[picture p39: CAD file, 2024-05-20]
CAD/SmarsMicrobit/Sensores/SensorCapacitivo/ut2.stl
35.6 x 7.00 x 20.1

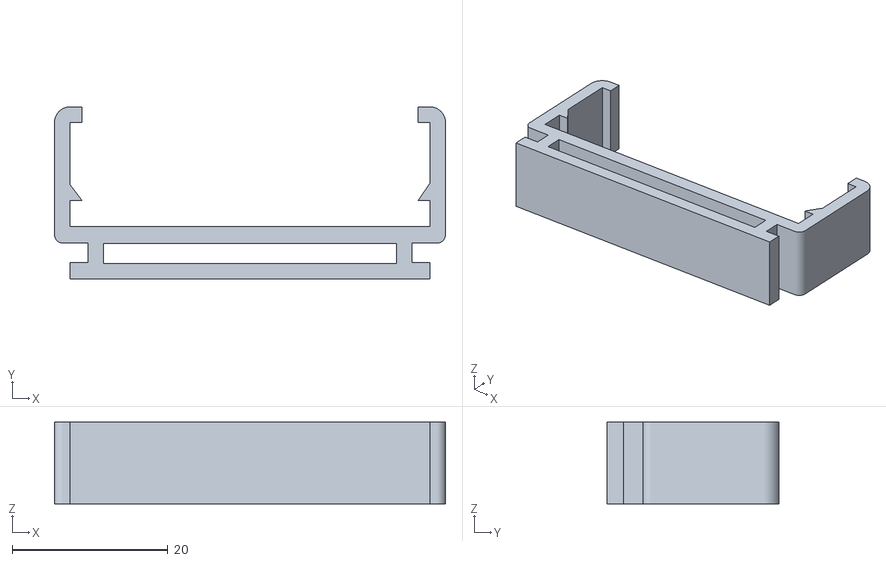
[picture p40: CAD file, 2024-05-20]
CAD/SmarsMicrobit/Sensores/SensorUltrasonidos/ultrasonic_2b_V2.stl
50.2 x 22.1 x 10.5

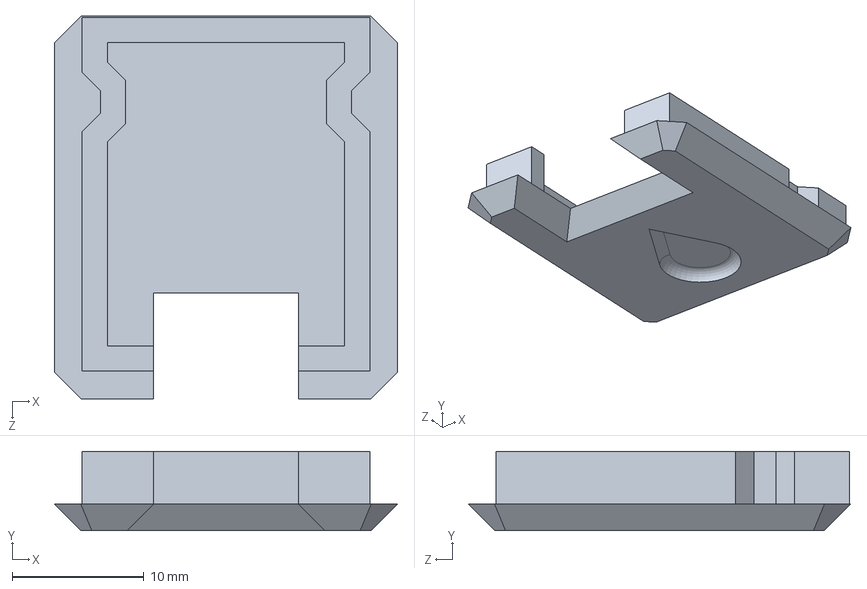
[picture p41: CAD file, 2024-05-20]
CAD/SmarsMicrobit/Sensores/SmarsSensorCapacitivoV0(NoUsar)/Solid/smarsCapacitive2.SLDPRT
26.0 x 6.00 x 29.0 mm

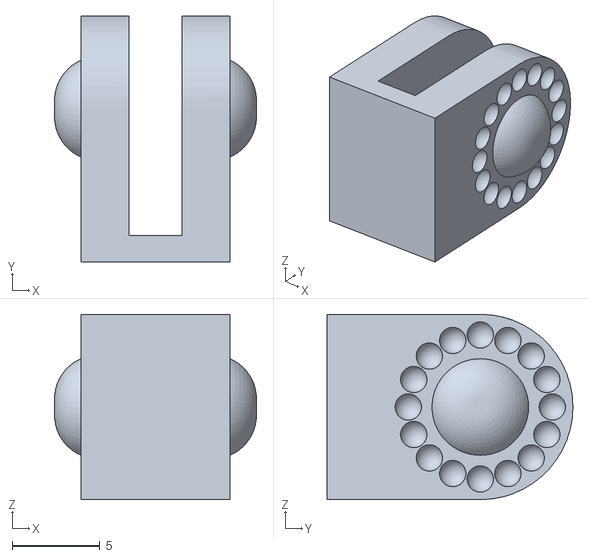
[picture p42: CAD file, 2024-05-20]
CAD/SmarsMicrobit/Sensores/SmarsSensorCapacitivoV0(NoUsar)/STL/smarsConnector.STL
11.5 x 14.0 x 10.5

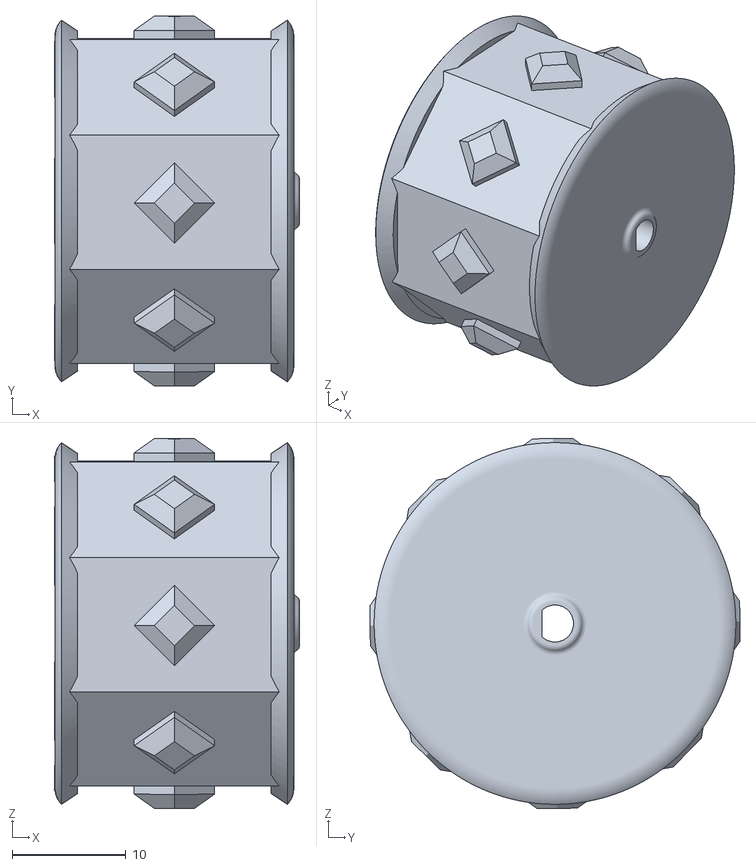
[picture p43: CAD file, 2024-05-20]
CAD/SmarsMicrobit/Chasis/DC/master_wheel.stl
21.5 x 32.5 x 32.5

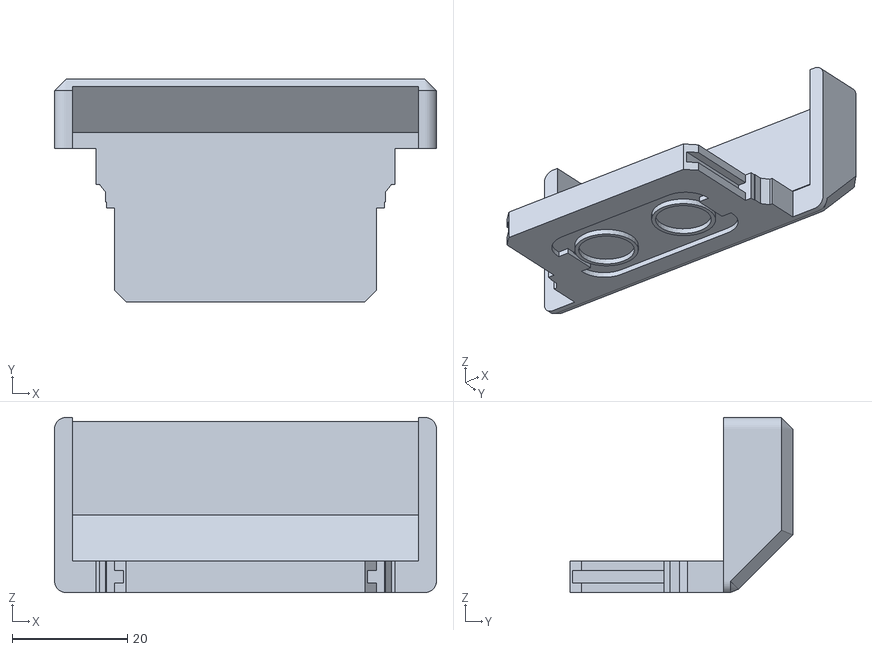
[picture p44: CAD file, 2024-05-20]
CAD/SmarsMicrobit/Chasis/PasoAPaso/SMARSTrunk.STL
66.3 x 38.7 x 30.4

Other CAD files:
CAD/SmarsMicrobit/Chasis/Servo/SMARS_servo_wheel.stl
CAD/SmarsMicrobit/CommonMicrobitPieces/slave_wheel_SL.stl
CAD/SmarsMicrobit/Sensores/Montacargas/fork_lift_a.stl
CAD/SmarsMicrobit/Sensores/SensorCapacitivo/holder_soil_moisture.stl
CAD/SmarsMicrobit/Chasis/PasoAPaso/SmarsMasterWheelStepper.stl
CAD/SmarsMicrobit/CommonMicrobitPieces/OrugaTPU/RuedaMicrobitTPU.STL
CAD/SmarsMicrobit/CommonMicrobitPieces/mechanical_track.stl
CAD/SmarsMicrobit/Sensores/Montacargas/fork_lift_b.stl
CAD/SmarsMicrobit/Sensores/Montacargas/fork_lift_e.stl
CAD/SmarsMicrobit/Sensores/Montacargas/fork_lift_f.stl
CAD/SmarsMicrobit/Sensores/SensorCapacitivo/SmarsCapacitiveEdit.stl
CAD/SmarsMicrobit/Sensores/SensorCapacitivo/fork_lift_e.stl
CAD/SmarsMicrobit/Sensores/SensorCapacitivo/fork_lift_f.stl
CAD/SmarsMicrobit/Sensores/SensorCapacitivo/smarsCapacitive2.STL
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

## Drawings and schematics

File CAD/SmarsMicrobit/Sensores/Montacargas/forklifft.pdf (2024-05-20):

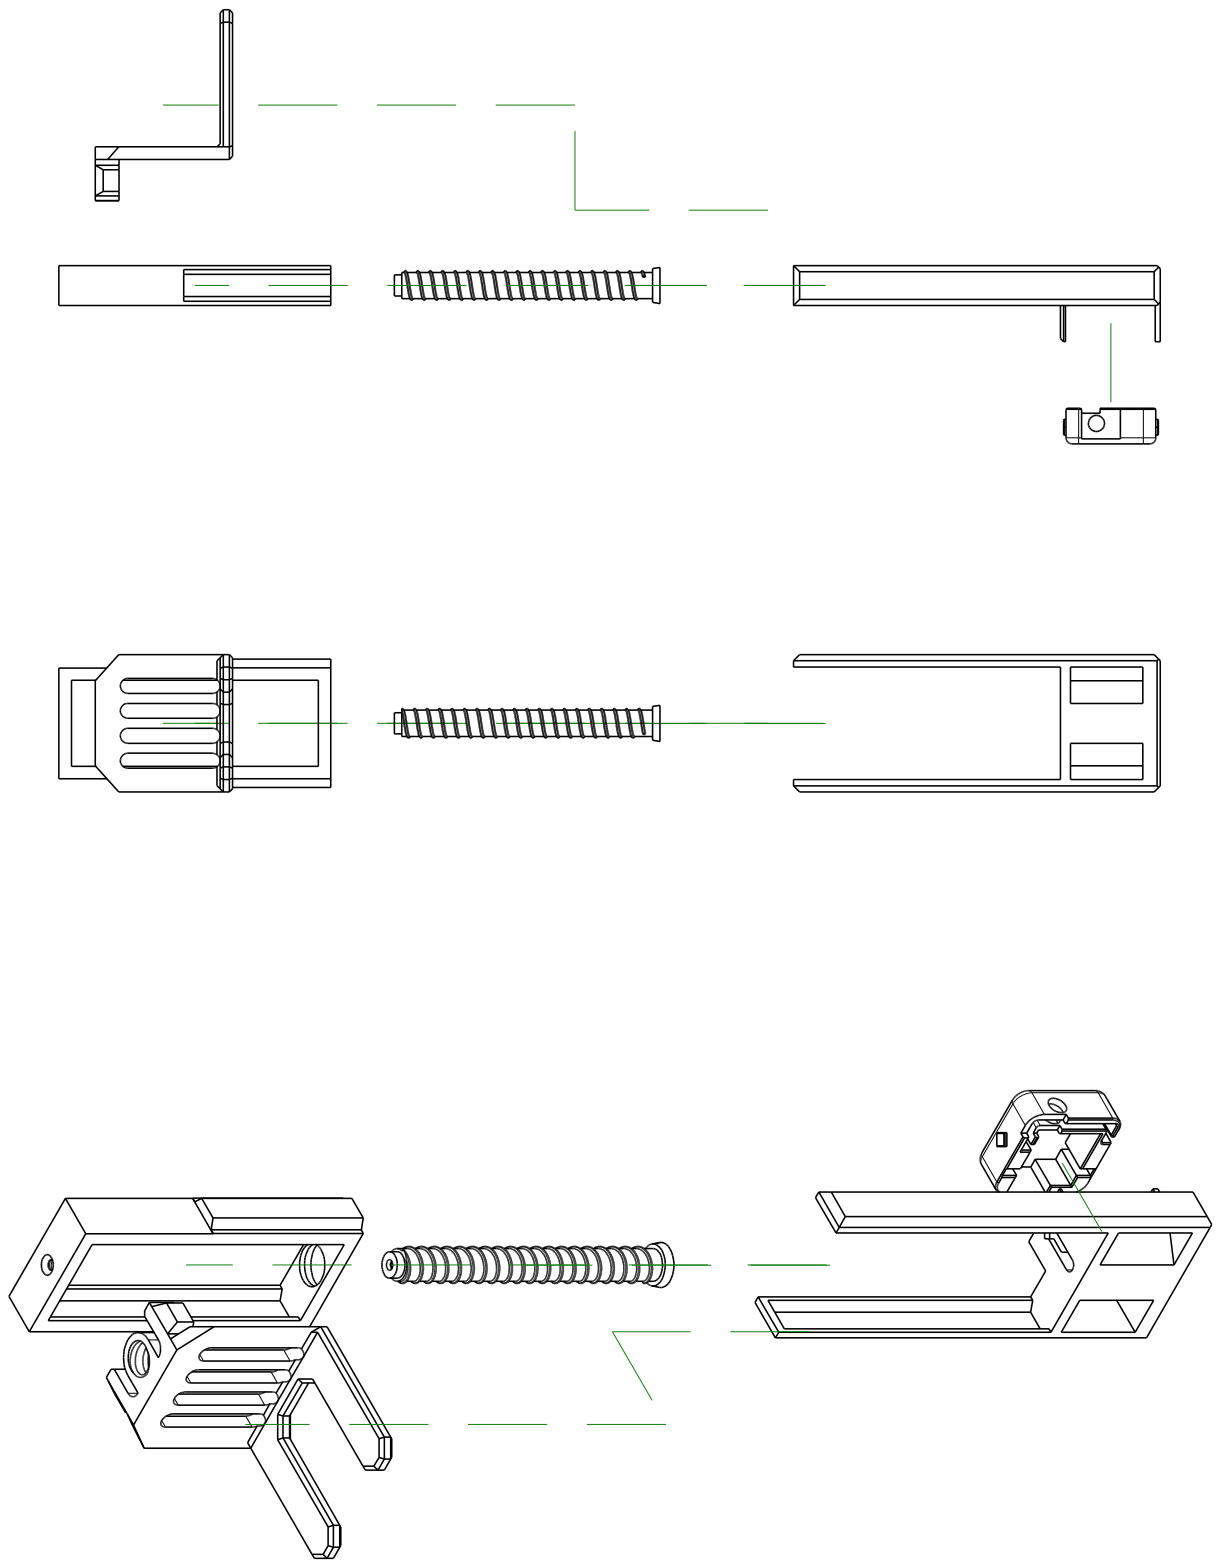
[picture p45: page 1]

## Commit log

2024-05-20 WIP
    WIP
    [ChassisDC.stl, ChassisServo.stl, ChassisStepper.STL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]
2024-05-20 Create STL Adicionales
2024-05-20 Rename STL Adicionales to STL Adicionales.txt
2024-07-11 ChassisDC update
    [ChassisDC.stl]
2024-07-11 ChassisStepper Update
    [ChassisStepper.stl]
2024-07-11 ChassisServo Update
    [ChassisServo.stl]
2024-07-11 BacaMicrobit rename to MicrobitHolder
    [MicrobitHolder.stl]
